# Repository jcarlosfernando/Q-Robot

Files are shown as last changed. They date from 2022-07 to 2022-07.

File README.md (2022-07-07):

# Q-Robot

Q-Robot is a versatile open-source Quadruped Robot developed with affordable electronic devices, with structural parts printed in PLA from 3D printers, integrating Robot Operating System (ROS) and Wi-Fi connection. The project aims to present a model with significantly reduced cost, to use only standard components and straightforward fabrication, aiming its use for educational purposes.

Inspired by the famous fourlegged robot from Boston Dynamics, Spot Mini, Q-Robot is an adaptation of a model developed by Kim Deok-Yeon, named Spot Micro.

Q-Robot uses ROS packages [rosserial](http://wiki.ros.org/rosserial) and [CHAMP](https://github.com/chvmp/champ#champ-) to works.



Tested on Ubuntu 18.04 with ROS Melodic 1.14.13

## Instructions

1 - Install rosserial package folowing this instructions [here](http://wiki.ros.org/rosserial);

2 - Install CHAMP package folowing this instructions [here](https://github.com/chvmp/champ#champ-);

3 - Follow the instructions to create your own robot using [champ_setup_assistent](https://github.com/chvmp/champ_setup_assistant);

4 - Running the rosserial package:

* cd <your_ws>/
* catkin_make
* source devel/setup.bash
* roslaunch rosserial_server socket.launch

5 - Open another terminal and running the CHAMP package of your robot configuration:

* cd <your_ws>/
* catkin_make
* source devel/setup.bash
* roslaunch <myrobot_config> bringup.launch

6 - To control your robot by laptop's keybord, run the teleop node:

* cd <your_ws>/
* catkin_make
* source devel/setup.bash
* roslaunch champ_teleop teleop.launch

If you want to use a joystick add joy:=true as an argument on the last command line:

* roslaunch champ_teleop teleop.launch joy:=true

7 - To autonoumus mode, with the Fuzzy obstacle avoidance, run the Matlab code "Autonomous_Mode.m", in folder "Q-Robot_Autonomous_Mode".

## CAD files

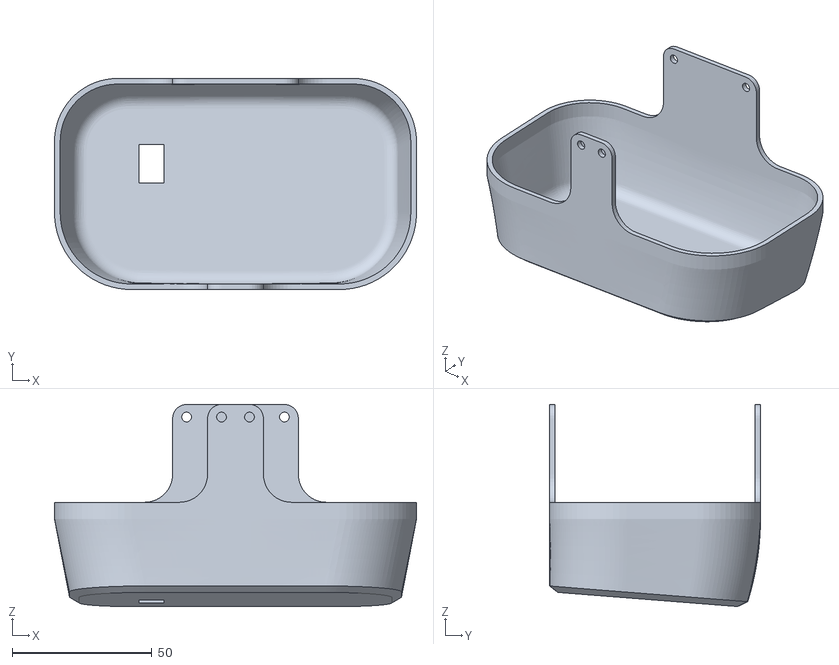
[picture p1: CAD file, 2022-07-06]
STLs_Q-Robot/Cover_Back.stl
129.5 x 75.5 x 72.3

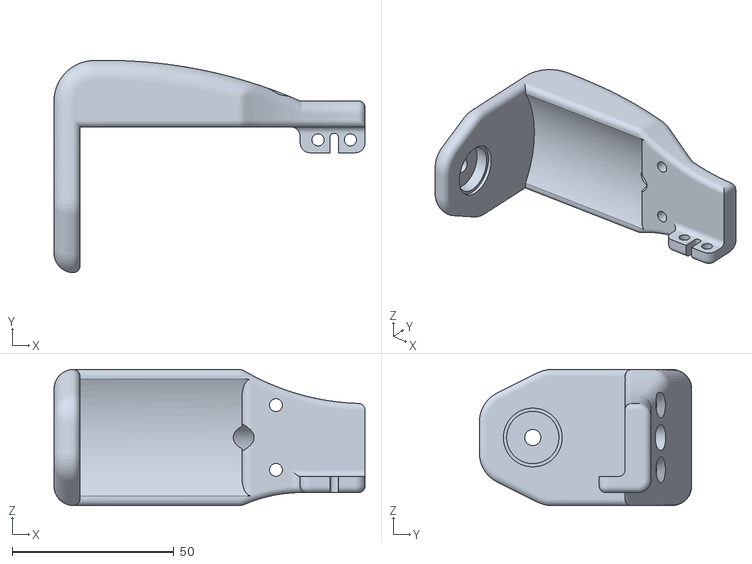
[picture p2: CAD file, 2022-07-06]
STLs_Q-Robot/L_Sholder_Pad.stl
96.0 x 65.5 x 42.0

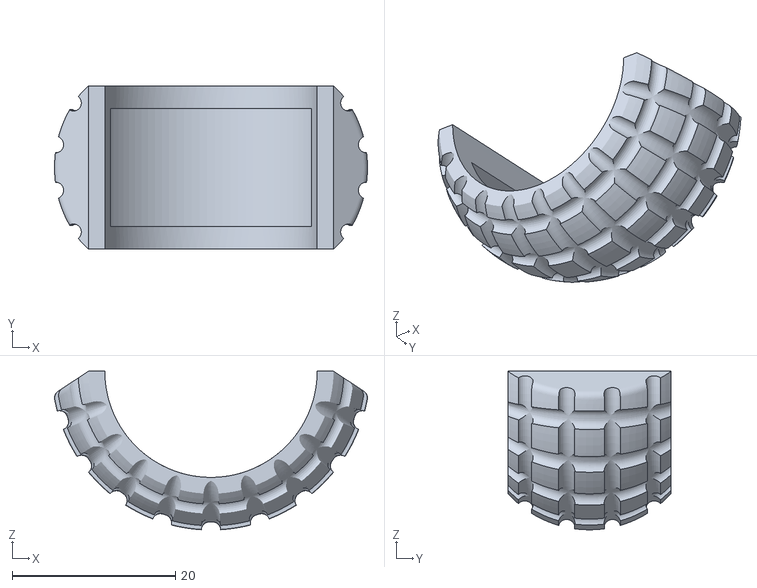
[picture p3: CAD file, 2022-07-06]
STLs_Q-Robot/Foot.stl
38.3 x 20.0 x 19.4

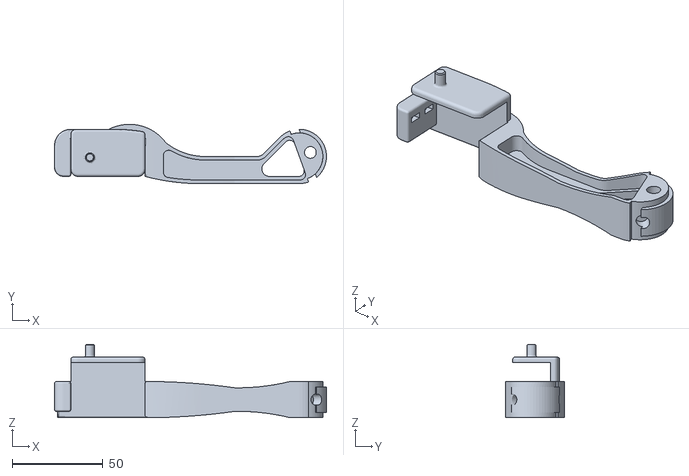
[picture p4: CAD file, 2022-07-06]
STLs_Q-Robot/L_Lower_Limb.stl
150.0 x 32.7 x 40.5

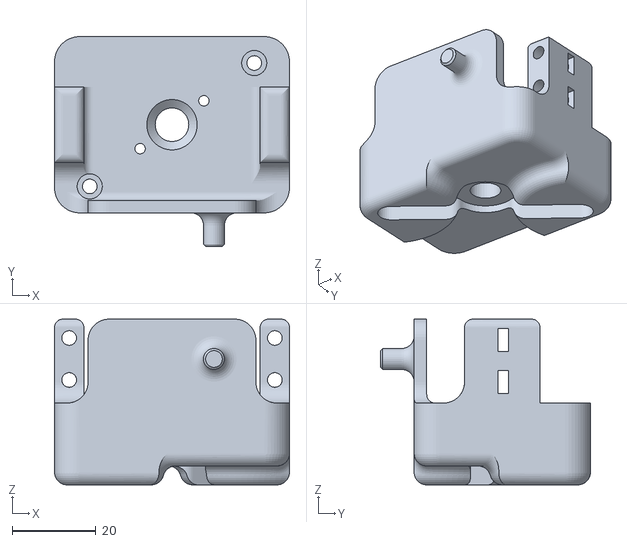
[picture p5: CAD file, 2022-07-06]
STLs_Q-Robot/R_Sholder.stl
56.0 x 50.0 x 39.5

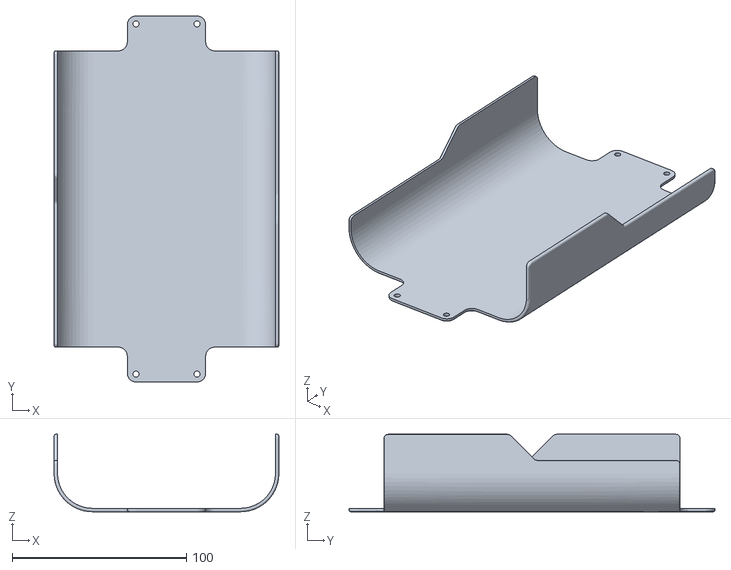
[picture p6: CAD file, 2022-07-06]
STLs_Q-Robot/Cover_Upper.stl
129.0 x 210.0 x 44.5

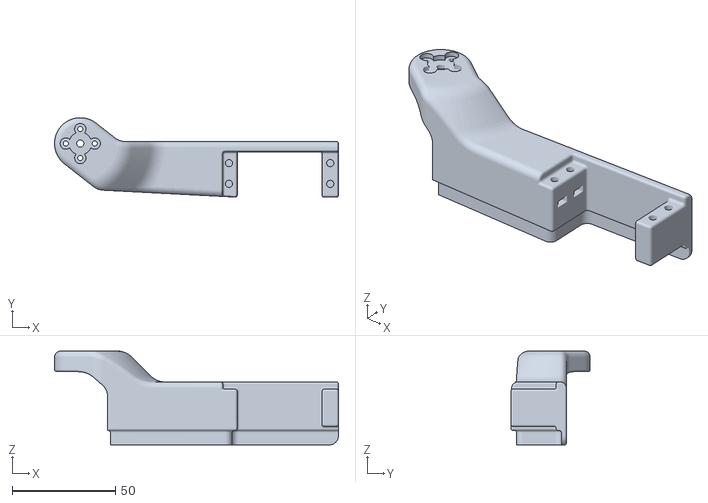
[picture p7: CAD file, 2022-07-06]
STLs_Q-Robot/R_Upper_Limb.stl
137.5 x 38.5 x 45.5

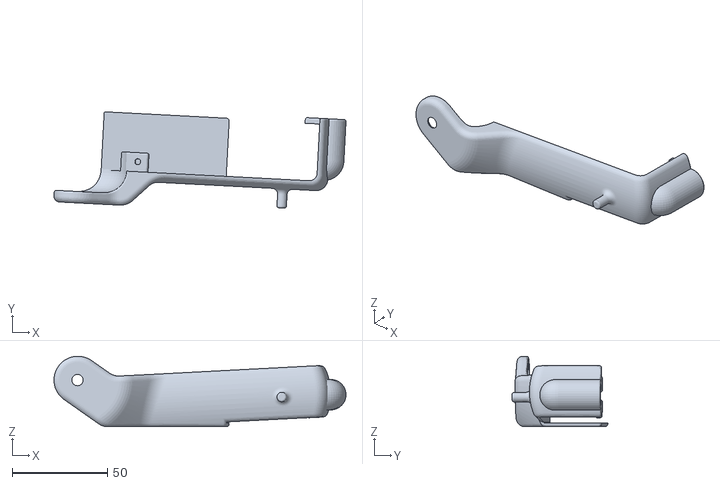
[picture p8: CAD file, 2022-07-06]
STLs_Q-Robot/L_Paw_Cover.stl
153.2 x 50.4 x 37.0

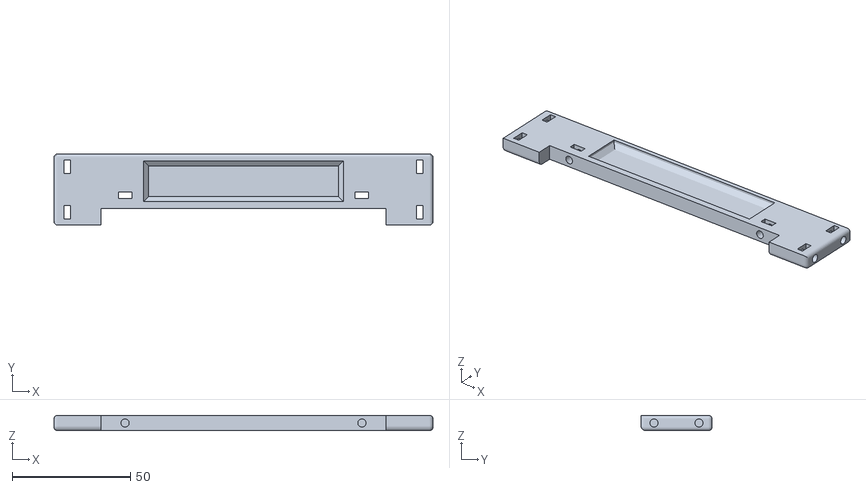
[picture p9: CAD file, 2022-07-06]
STLs_Q-Robot/Side_Plate.stl
160.0 x 30.0 x 6.50

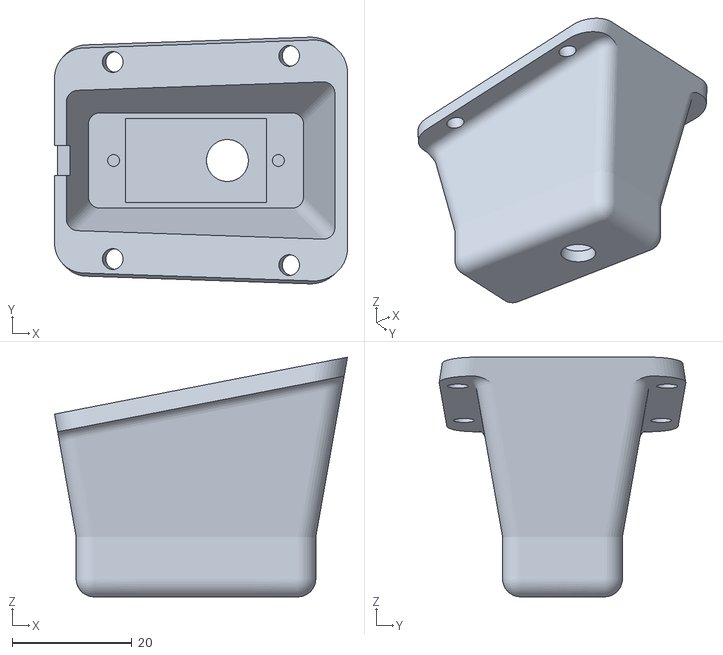
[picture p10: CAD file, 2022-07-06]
STLs_Q-Robot/Base_Lidar.stl
48.9 x 41.2 x 40.0

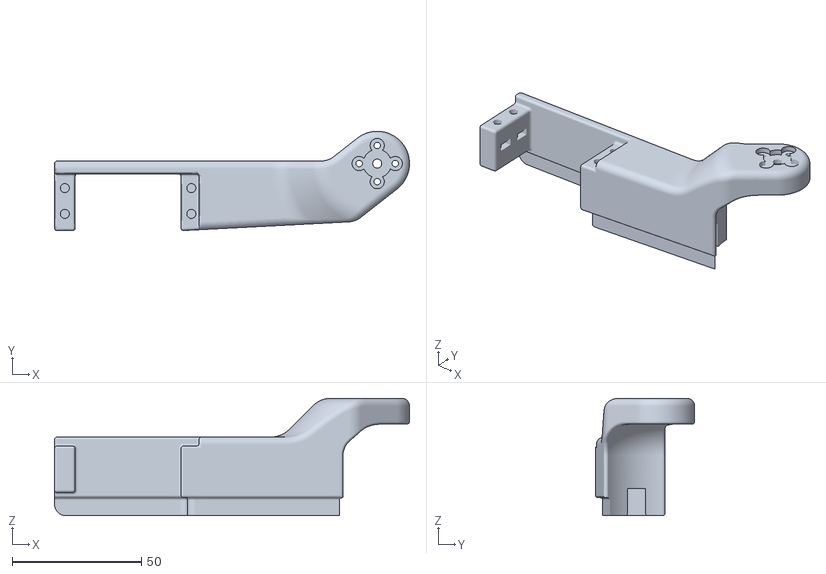
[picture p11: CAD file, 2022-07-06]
STLs_Q-Robot/L_Upper_Limb.stl
137.5 x 38.5 x 45.5

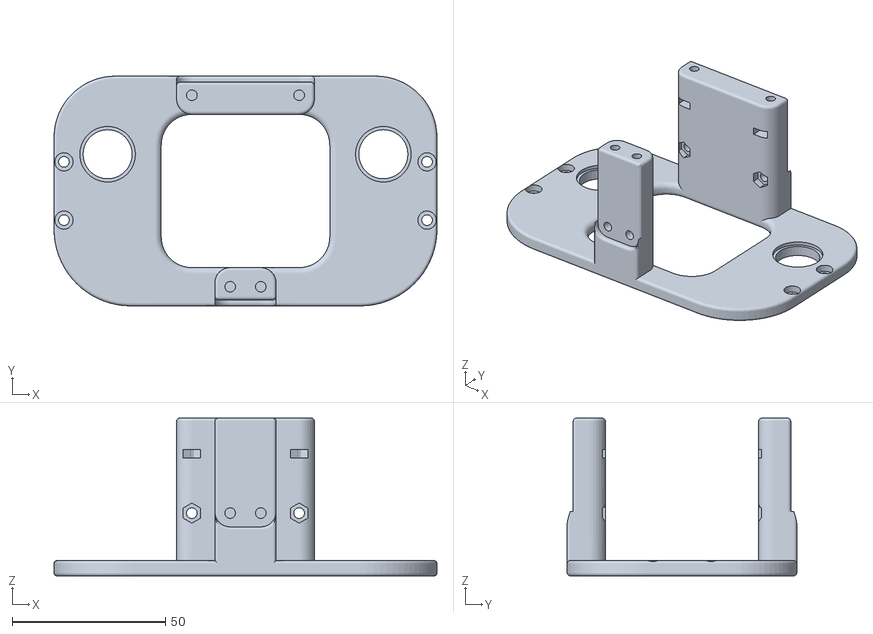
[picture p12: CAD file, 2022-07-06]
STLs_Q-Robot/Inter_Part1.stl
125.0 x 75.0 x 51.5

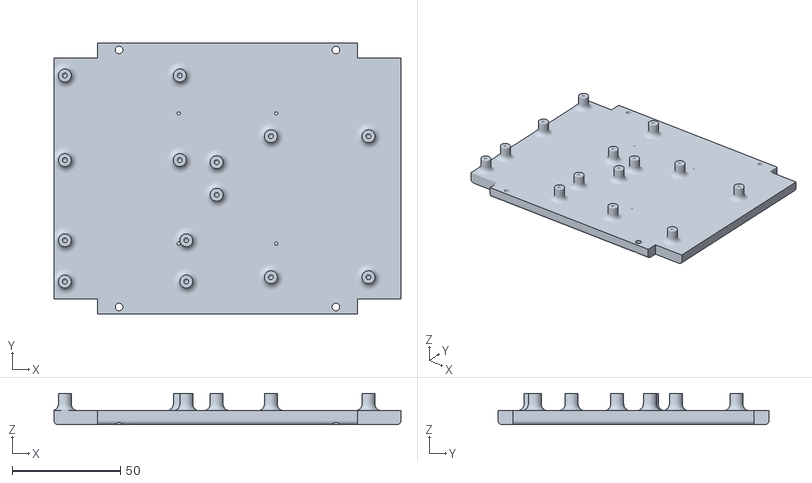
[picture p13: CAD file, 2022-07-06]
STLs_Q-Robot/Plate.stl
160.0 x 125.0 x 14.5

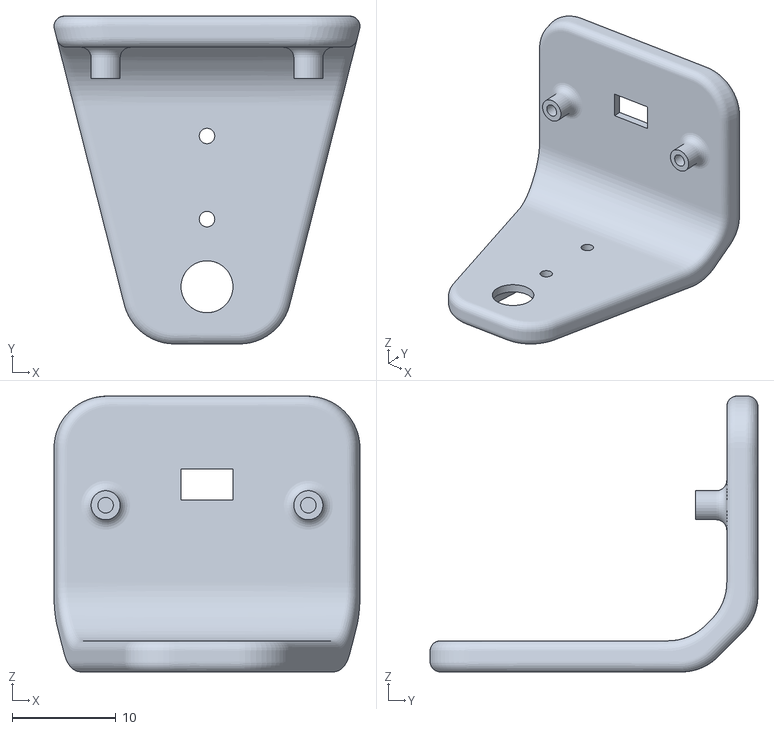
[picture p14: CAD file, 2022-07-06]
STLs_Q-Robot/Laser_Support.stl
29.4 x 31.5 x 26.5

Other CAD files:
STLs_Q-Robot/R_Lower_Limb.stl
STLs_Q-Robot/R_Sholder_Pad.stl
STLs_Q-Robot/L_Sholder.stl
STLs_Q-Robot/R_Paw_Cover.stl
3Dfiles_Q-Robot/Ante_Braço_Dir.ipt
3Dfiles_Q-Robot/Ante_Braço_Esq.ipt
3Dfiles_Q-Robot/Base_Componentes_Arduino_v3.ipt
3Dfiles_Q-Robot/Base_Lidarv2.ipt
3Dfiles_Q-Robot/Braço_Dir.ipt
3Dfiles_Q-Robot/Braço_Esq.ipt
3Dfiles_Q-Robot/Circle Rudder.ipt
3Dfiles_Q-Robot/Clavicula.iam
3Dfiles_Q-Robot/Corpo_Interno_v3.iam
3Dfiles_Q-Robot/Cover_Braço_Dir_v13.ipt
3Dfiles_Q-Robot/Cover_Braço_Dir_v3.ipt
3Dfiles_Q-Robot/Cover_Braço_Esq_v3.ipt
3Dfiles_Q-Robot/Cover_Dianteira.ipt
3Dfiles_Q-Robot/Cover_Inferior.ipt
3Dfiles_Q-Robot/Cover_Superior.ipt
3Dfiles_Q-Robot/Cover_Traseira.ipt
3Dfiles_Q-Robot/Estrutura_Corpo_Interno.ipt
3Dfiles_Q-Robot/Fechamento_Corpo.ipt
3Dfiles_Q-Robot/Foot.ipt
3Dfiles_Q-Robot/LF20MG.ipt
3Dfiles_Q-Robot/Lateral.ipt
3Dfiles_Q-Robot/Lateral_LadoUSB.ipt
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

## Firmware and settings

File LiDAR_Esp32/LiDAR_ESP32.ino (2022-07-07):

#include <Wire.h>
#include <VL53L0X.h>
#include <ESP32Servo.h>

#include <WiFi.h>
#define ROSSERIAL_ARDUINO_TCP
#include <ros.h>
#include <sensor_msgs/LaserScan.h>

VL53L0X sensor;
Servo myservo;

// Set the WiFi's username and password
const char* ssid = "WiFi's username";
const char* password = "password";

// Set the rosserial socket server IP address
IPAddress server(192, 168, 1, 76);

// Set the rosserial socket server port
const uint16_t serverPort = 11411;

#define ang_incr 5 // Incremento do ângulo [graus]
#define n_pont 30 // Número máximo de leituras (Os testes mostram que *50* é o número máximo suportado pelo rosserial)
float ranges[n_pont] = {0};
float intensities[n_pont] = {0};
int ang_varr = ang_incr * n_pont; // Varredura em graus
int ang_min = (180 - ang_varr) / 2; // Ângulo mínimo [graus]
int ang_max = ang_varr + ang_min; // Ângulo máximo [graus]

int count, p, s;
int servoPin = 13; int pos = ang_min;
float dist, time_Now, time_Later, Scan_time;

ros::NodeHandle nh;

sensor_msgs::LaserScan msg_lidar;
ros::Publisher pub_lidar("/laser_scan", &msg_lidar);

void setup()
{
  Serial.begin(57600);

  myservo.setPeriodHertz(60);    // standard 60 hz servo
  myservo.attach(servoPin, 500, 2500);

  Wire.begin();

  //********************************************************************
  sensor.setTimeout(500);
  sensor.init();

  // lower the return signal rate limit (default is 0.25 MCPS)
  sensor.setSignalRateLimit(0.1);

  // increase laser pulse periods (defaults are 14 and 10 PCLKs)
  sensor.setVcselPulsePeriod(VL53L0X::VcselPeriodPreRange, 18);
  sensor.setVcselPulsePeriod(VL53L0X::VcselPeriodFinalRange, 14);

  // increase timing budget to 200 ms
  sensor.setMeasurementTimingBudget(20000);

  //*********************************************************************
  // Trecho de conexão com WiFi
  Serial.print("Connecting to : ");
  Serial.println(ssid);

  WiFi.persistent(false);
  WiFi.mode(WIFI_OFF);
  WiFi.mode(WIFI_STA);

  WiFi.disconnect();
  WiFi.begin(ssid, password);
  while (WiFi.status() != WL_CONNECTED) {
    delay(500);
    Serial.print(".");
  }

  if (WiFi.status() == WL_CONNECTED) {
    Serial.println("WifiOK");
  }

  Serial.println("Connection established!");
  Serial.print("IP address: ");
  Serial.println(WiFi.localIP());

  //Trecho ROS
  // Set the connection to rosserial socket server
  nh.getHardware()->setConnection(server, serverPort);
  nh.initNode();

  // Montando a mensagem laser_scan
  msg_lidar.header.frame_id = "LiDar";
  msg_lidar.angle_min = ang_min * (3.14 / 180); // Mínimo ãngulo de varredura [rad]
  msg_lidar.angle_max = ang_max * (3.14 / 180); // Máximo ângulo de varredura [rad]
  msg_lidar.angle_increment = ang_incr * 3.14 / 180; // Incremento angular [rad]
  msg_lidar.range_min = 0.01; // Distãncia mínima de leitura do laser [m]
  msg_lidar.range_max = 2.0; // Distância máxima de leitura do laser [m]
  msg_lidar.time_increment = 0.001; // Tempo entre cada leitura [seg]
  msg_lidar.ranges_length = n_pont;
  msg_lidar.intensities_length = n_pont;

  nh.advertise(pub_lidar);

  myservo.write(ang_min);
  delay(1000);
}

void loop()
{
  if (nh.connected()) {
    myservo.write(pos);
    time_Later = millis();
    dist = sensor.readRangeSingleMillimeters();
    //Serial.println(dist);
    ranges[count] = dist * 0.001;
    time_Now = millis();
    Scan_time = time_Now - time_Later;
  }
  // Atualiza os valores da msg e publica
  msg_lidar.scan_time = Scan_time / 100000;
  msg_lidar.ranges = ranges;
  msg_lidar.intensities = intensities;

  pub_lidar.publish( &msg_lidar);

  nh.spinOnce();

  count = count + p;
  pos = pos + s;
  //Serial.println(pos);
  if (count == 0) {
    p  = 1;
    s = ang_incr;
  }
  else if (count == n_pont) {
    p = -1;
    s = -1*ang_incr;
  }
}

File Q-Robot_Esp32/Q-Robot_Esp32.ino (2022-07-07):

#include <Wire.h>
#include <Adafruit_PWMServoDriver.h>

#include <WiFi.h>
#define ROSSERIAL_ARDUINO_TCP
#include <ros.h>
#include <std_msgs/Float32.h>
#include <trajectory_msgs/JointTrajectory.h>
#include <std_msgs/Float64.h>

float serv[12];

// Set the WiFi's username and password
const char* ssid = "WiFi's username";
const char* password = "Password";

// Set the rosserial socket server IP address
IPAddress server(192, 168, 1, 76);

// Set the rosserial socket server port
const uint16_t serverPort = 11411;

ros::NodeHandle nh;
// Make a chatter publisher
//std_msgs::String str_msg;
//ros::Publisher chatter("chatter", &str_msg);

// Ros Publishers
//std_msgs::Float32 msg_acel_x;
//ros::Publisher pub_acelx("/AcelX", &msg_acel_x);
//
//std_msgs::Float32 msg_acel_y;
//ros::Publisher pub_acely("/AcelY", &msg_acel_y);
//
//std_msgs::Float32 msg_acel_z;
//ros::Publisher pub_acelz("/AcelZ", &msg_acel_z);

//ros::Subscriber <geometry_msgs::Twist> sub("/cmd_vel", Callback);
void Callback0(const trajectory_msgs::JointTrajectory& Tr_msg) {
  for (int i = 0; i < 12; i++) {
    serv[i] = Tr_msg.points[0].positions[i];
    serv[i] = serv[i] * 57.3;
  }
}

ros::Subscriber <trajectory_msgs::JointTrajectory> sub0("/joint_group_position_controller/command", Callback0);

//Endereco I2C do MPU6050
const int MPU = 0x68; //pino aberto 0X68 , pino ligado em 3,3V 0x69
int acelX, acelY, acelZ, giroX, giroY, giroZ;
//float ang_accel, vang_gyro;

Adafruit_PWMServoDriver pwm = Adafruit_PWMServoDriver(0x40, Wire);

int pos;

void setup() {
  Serial.begin(57600);

  // Trecho de inicialização dos motores
  pwm.begin();
  pwm.setPWMFreq(60);

  // Trecho de inicialização do MPU6050
  Wire.begin();                 //inicia I2C
  Wire.beginTransmission(MPU);  //Inicia transmissão para o endereço do MPU
  Wire.write(0x6B);
  Wire.write(0);
  Wire.endTransmission(true);

  // Trecho de conexão com a Internet
  Serial.print("Connecting to : ");
  Serial.println(ssid);

  WiFi.persistent(false);
  WiFi.mode(WIFI_OFF);
  WiFi.mode(WIFI_STA);

  WiFi.disconnect();
  WiFi.begin(ssid, password);
  while (WiFi.status() != WL_CONNECTED) {
    delay(500);
    Serial.print(".");
  }

  if (WiFi.status() == WL_CONNECTED) {
    Serial.println("WifiOK");
  }

  Serial.println("Connection established!");
  Serial.print("IP address: ");
  Serial.println(WiFi.localIP());

  //Trecho ROS
  // Set the connection to rosserial socket server
  nh.getHardware()->setConnection(server, serverPort);
  nh.initNode();

//  nh.advertise(pub_acelx);
//  nh.advertise(pub_acely);
//  nh.advertise(pub_acelz);

  nh.subscribe(sub0);
}

void loop() {
  //delay(20);
  nh.spinOnce();
  if (nh.connected()) {
    //MPU6050(); // Aquisição dos dados do Acelerometro e Giroscópio.
    Motors_ON(serv[0], serv[1], serv[2], serv[3], serv[4], serv[5], serv[6], serv[7], serv[8], serv[9], serv[10], serv[11]);
  }
}

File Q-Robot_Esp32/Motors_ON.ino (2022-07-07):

//int last_ang0, last_ang1, last_ang2, last_ang3, last_ang4, last_ang5, last_ang6, last_ang7, last_ang8, last_ang9, last_ang10, last_ang11;
//int pos;
void Motors_ON(int ang0, int ang1, int ang2, int ang3, int ang4, int ang5, int ang6, int ang7, int ang8, int ang9, int ang10, int ang11) {

//
      ang0 = abs(68 - ang0);
//      if ((ang0 == 0 || ang0 == 180 || abs(ang0 - last_ang0) >= 20) && (last_ang0 > 0)) {
//        ang0 = last_ang0;
//      }
//      else{
//        last_ang0 = ang0;
//      }
      pos = map(ang0, 0, 165, 500, 2600);
      pwm.writeMicroseconds(2, pos);


      ang1 = abs(83 + ang1); // Correção
//      if ((ang1 == 0 || ang1 == 180 || abs(ang1 - last_ang1) >= 20) && (last_ang1 > 0)) {
//        ang1 = last_ang1;
//      }
//      else{
//        last_ang1 = ang1;
//      }
      pos = map(ang1, 0, 165, 500, 2600);
      pwm.writeMicroseconds(1, pos);

      ang2 = abs(115 + ang2);
//      if ((ang2 == 0 || ang2 == 180 || abs(ang2 - last_ang2) >= 20) && (last_ang2 > 0)) {
//        ang2 = last_ang2;
//      }
//      else{
//        last_ang2 = ang2;
//      }
      pos = map(ang2, 0, 165, 500, 2600);
      pwm.writeMicroseconds(0, pos);
      
      ang3 = abs(78 - ang3);
//      if ((ang3 == 0 || ang3 == 180 || abs(ang3 - last_ang3) >= 20) && (last_ang3 > 0)) {
//        ang3 = last_ang3;
//      }
//      else{
//        last_ang3 = ang3;
//      }
      pos = map(ang3, 0, 165, 500, 2600);
      pwm.writeMicroseconds(3, pos);
//
      ang4 = abs(72 - ang4);
//      if ((ang4 == 0 || ang4 == 180 || abs(ang4 - last_ang4) >= 20) && (last_ang4 > 0)) {
//        ang4 = last_ang4;
//      }
//      else{
//        last_ang4 = ang4;
//      }
      pos = map(ang4, 0, 165, 500, 2600);
      pwm.writeMicroseconds(4, pos);
//
      ang5 = abs(54 - ang5);
//      if ((ang5 == 0 || ang5 == 180 || abs(ang5 - last_ang5) >= 20) && (last_ang5 > 0)) {
//        ang5 = last_ang5;
//      }
//      else{
//        last_ang5 = ang5;
//      }
      pos = map(ang5, 0, 165, 500, 2600);
      pwm.writeMicroseconds(5, pos);
//
      ang6 = abs(92 - ang6);
//      if ((ang6 == 0 || ang6 == 180 || abs(ang6 - last_ang6) >= 20) && (last_ang6 > 0)) {
//        ang6 = last_ang6 + 1;
//      }
//      else{
//        last_ang6 = ang6;
//      }
      pos = map(ang6, 0, 180, 500, 2500);
      pwm.writeMicroseconds(12, pos);
//
      ang7 = abs(58 + ang7); // ><
//      if ((ang7 == 0 || ang7 == 180 || abs(ang7 - last_ang7) >= 20) && (last_ang7 > 0)) {
//        ang7 = last_ang7;
//      }
//      else{
//        last_ang7 = ang7;
//      }
      pos = map(ang7, 0, 165, 500, 2600);
      pwm.writeMicroseconds(11, pos);
//
      ang8 = abs(48 + ang8);
//      if ((ang8 == 0 || ang8 == 180 || abs(ang8 - last_ang8) >= 20) && (last_ang8 > 0)) {
//        ang8 = last_ang8;
//      }
//      else{
//        last_ang8 = ang8;
//      }
      pos = map(ang8, 0, 165, 500, 2600);
      pwm.writeMicroseconds(10, pos);
//
      ang9 = abs(102 - ang9);
//      if ((ang9 == 0 || ang9 == 180 || abs(ang9 - last_ang9) >= 20) && (last_ang9 > 0)) {
//        ang9 = last_ang9;
//      }
//      else{
//        last_ang9 = ang9;
//      }
      pos = map(ang9, 0, 180, 500, 2500);
      pwm.writeMicroseconds(13, pos);
//
      ang10 = abs(79 - ang10);
//      if ((ang10 == 0 || ang10 == 180 || abs(ang10 - last_ang10) >= 20) && (last_ang10 > 0)) {
//        ang10 = last_ang10;
//      }
//      else{
//        last_ang10 = ang10;
//      }
      pos = map(ang10, 0, 165, 500, 2600);
      pwm.writeMicroseconds(14, pos);
//
      ang11 = abs(112 - ang11);
//      if ((ang11 == 0 || ang11 == 180 || abs(ang11 - last_ang11) >= 20) && (last_ang11 > 0)) {
//        ang11 = last_ang11;
//      }
//      else{
//        last_ang11 = ang11;
//      }
      pos = map(ang11, 0, 165, 500, 2600);
      pwm.writeMicroseconds(15, pos);

//  Serial.print(ang0); Serial.print(", ");
//  Serial.print(ang1); Serial.print(", ");
//  Serial.print(ang2); Serial.print(", ");
//  Serial.print(ang3); Serial.print(", ");
//  Serial.print(ang4); Serial.print(", ");
//  Serial.print(ang5); Serial.print(", ");
//  Serial.print(ang6); Serial.print(", ");
//  Serial.print(ang7); Serial.print(", ");
//  Serial.print(ang8); Serial.print(", ");
//  Serial.print(ang9); Serial.print(", ");
//  Serial.print(ang10); Serial.print(", ");
//  Serial.println(ang11);
}
